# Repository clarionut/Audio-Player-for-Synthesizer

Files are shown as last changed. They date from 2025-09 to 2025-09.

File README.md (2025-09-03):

# Audio Player for Synthesizer
An audio player for a modular synthesizer based on a cheap 'Kebidu music speakers' module with FM radio, USB, micro SD, Bluetooth and aux-in modes.
This was inspired by the [Tesseract Modular 'Low Coast'](https://www.tesseractmodular.com/eurorack-modules/low-coast/) module which simply provides two Eurorack-level outputs, one for each of the stereo channels of the module.

This version also provides a mono mix output and has trigger inputs for the transport controls - play/pause, next station/track & previous station/track.

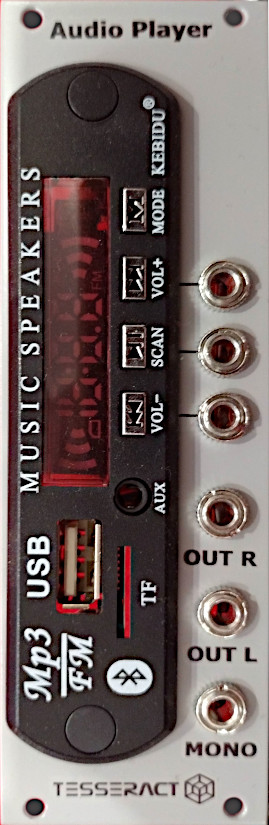
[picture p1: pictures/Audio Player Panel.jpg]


I'm not sure that this will be a particularly useful synth module, but I wanted to experiment using FETs as switches to allow external control. Somewhat to my surprise this works perfectly, with the switches being triggered by the rising edge of input pulses. Also the Kebidu units are very cheap - I got two for around £5 including shipping.

### Details
The Schematics folder contains pictures of the kicad schematic, the stripboard layout I used to build the module and a proposed PCB layout. There are several copper-side links (shown in blue) on the stripboard layout including two hard to see ones from pins 8 and 14 of the TL074 to the 100k resistors. Note that I haven't had the PCB fabricated, so use this layout at your own risk! The kicad project itself is in the AudioPlayer folder.

The only tricky part of the build was soldering the source and drain legs of the 2N7000 FETs across the switches. The solder pads are very small, so a fine-tipped soldering iron and a steady hand are needed! I've included a [photo showing the orientation of the FETs](https://github.com/clarionut/Audio-Player-for-Synthesizer/blob/main/pictures/Audio%20Player%20FETs.jpg) on my module. The correct orientation can be checked by measuring the voltage across each switch with a high impedance voltmeter. The drain of the FET is soldered to the more positive end of the switch, source to the negative end and the gate connected to the circuit board with a flying lead.

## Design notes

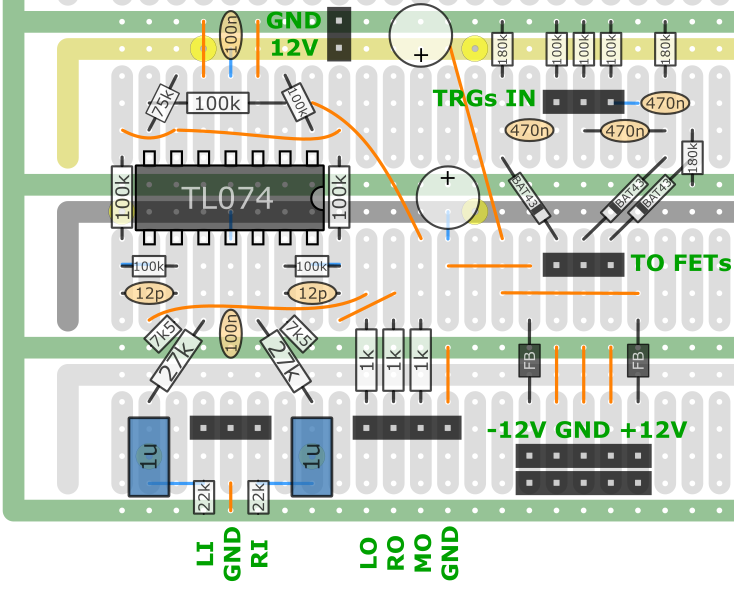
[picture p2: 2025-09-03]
schematics/layout.png

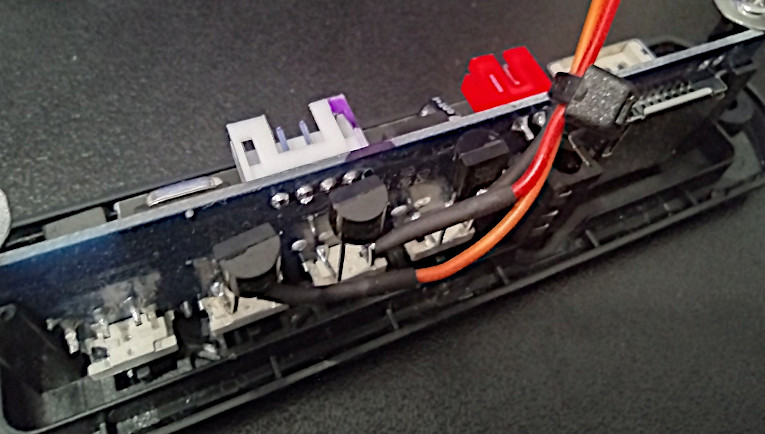
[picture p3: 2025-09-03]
pictures/Audio Player FETs.jpg

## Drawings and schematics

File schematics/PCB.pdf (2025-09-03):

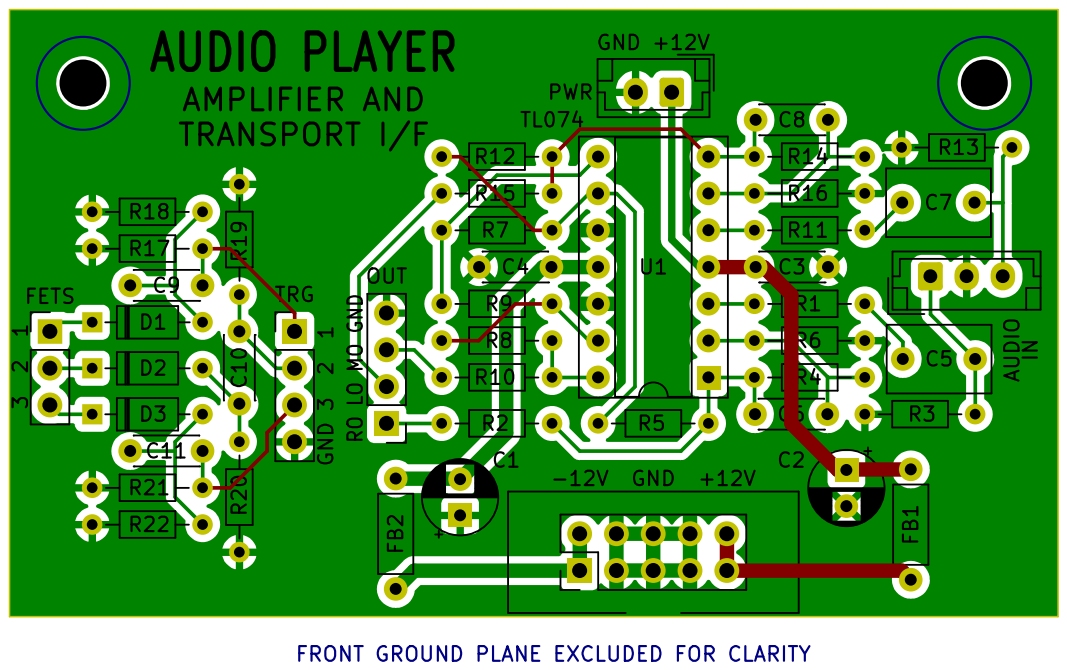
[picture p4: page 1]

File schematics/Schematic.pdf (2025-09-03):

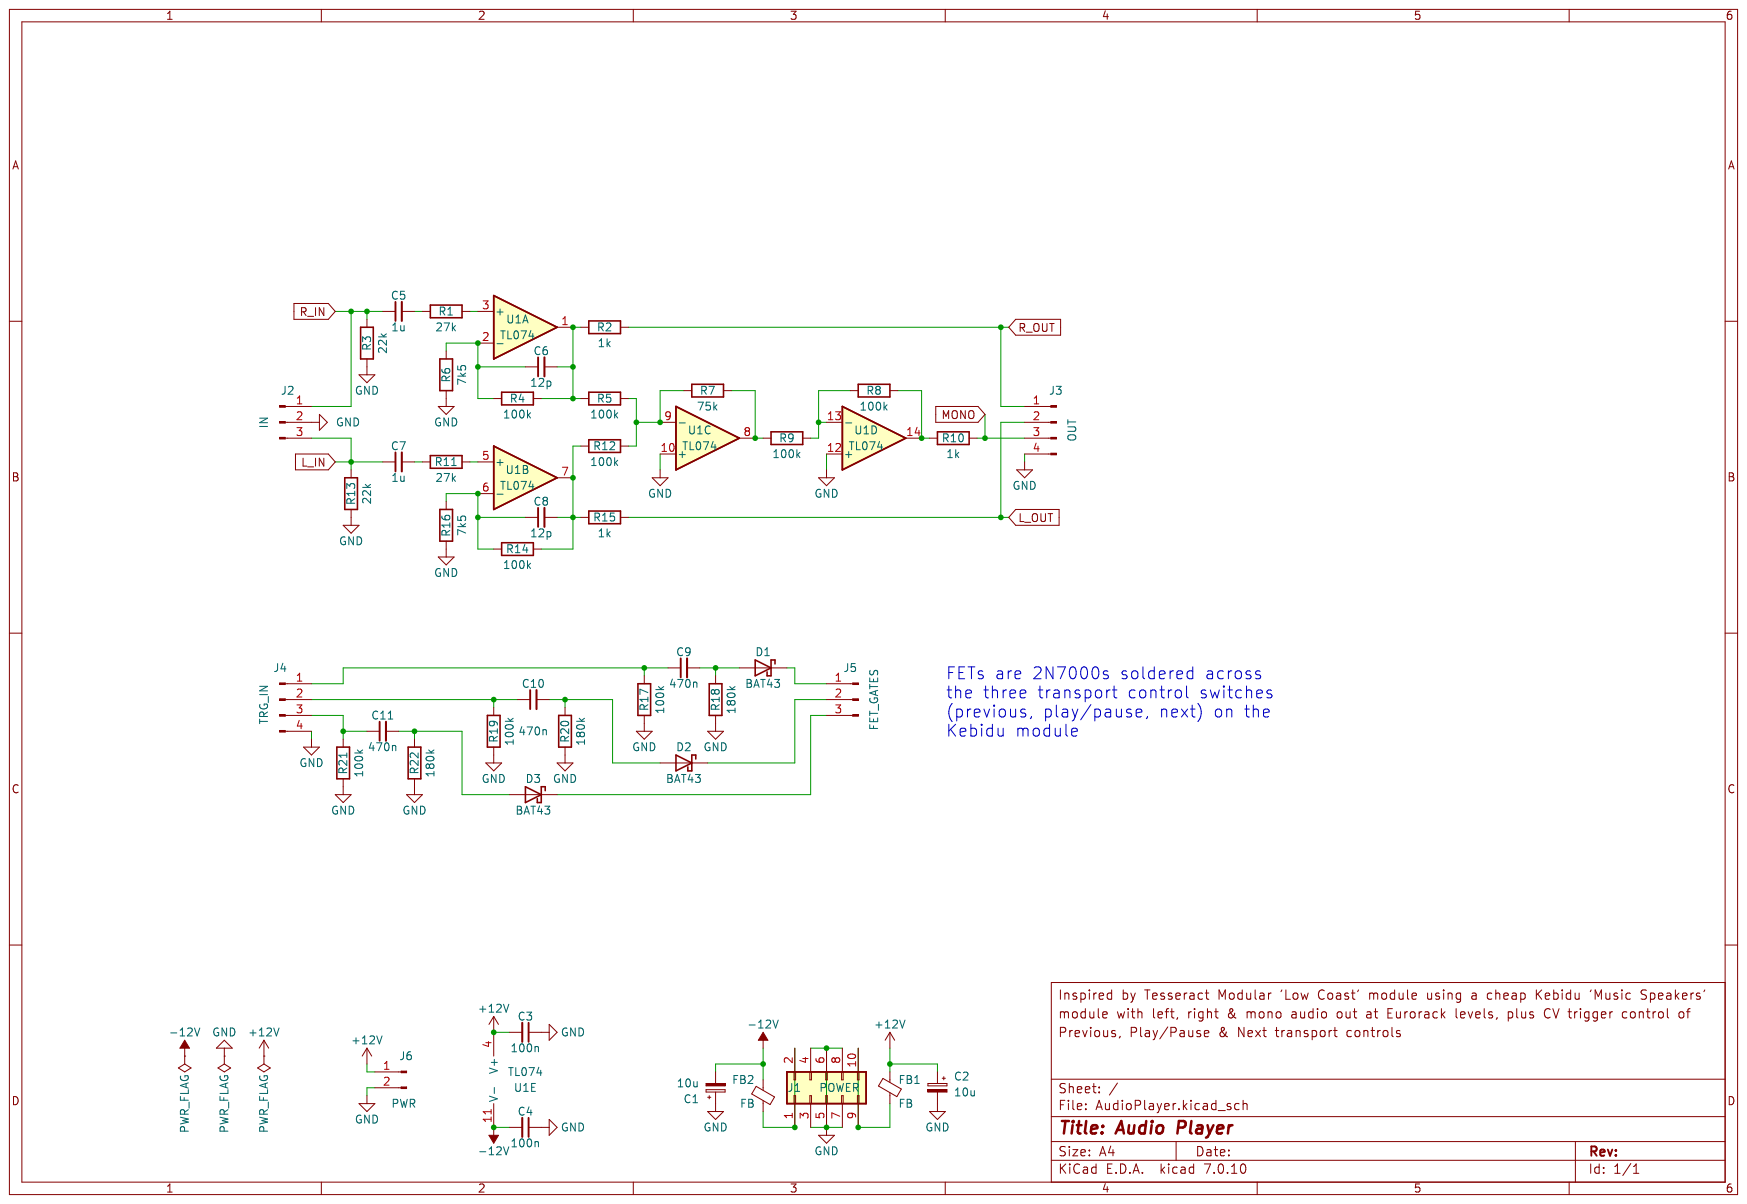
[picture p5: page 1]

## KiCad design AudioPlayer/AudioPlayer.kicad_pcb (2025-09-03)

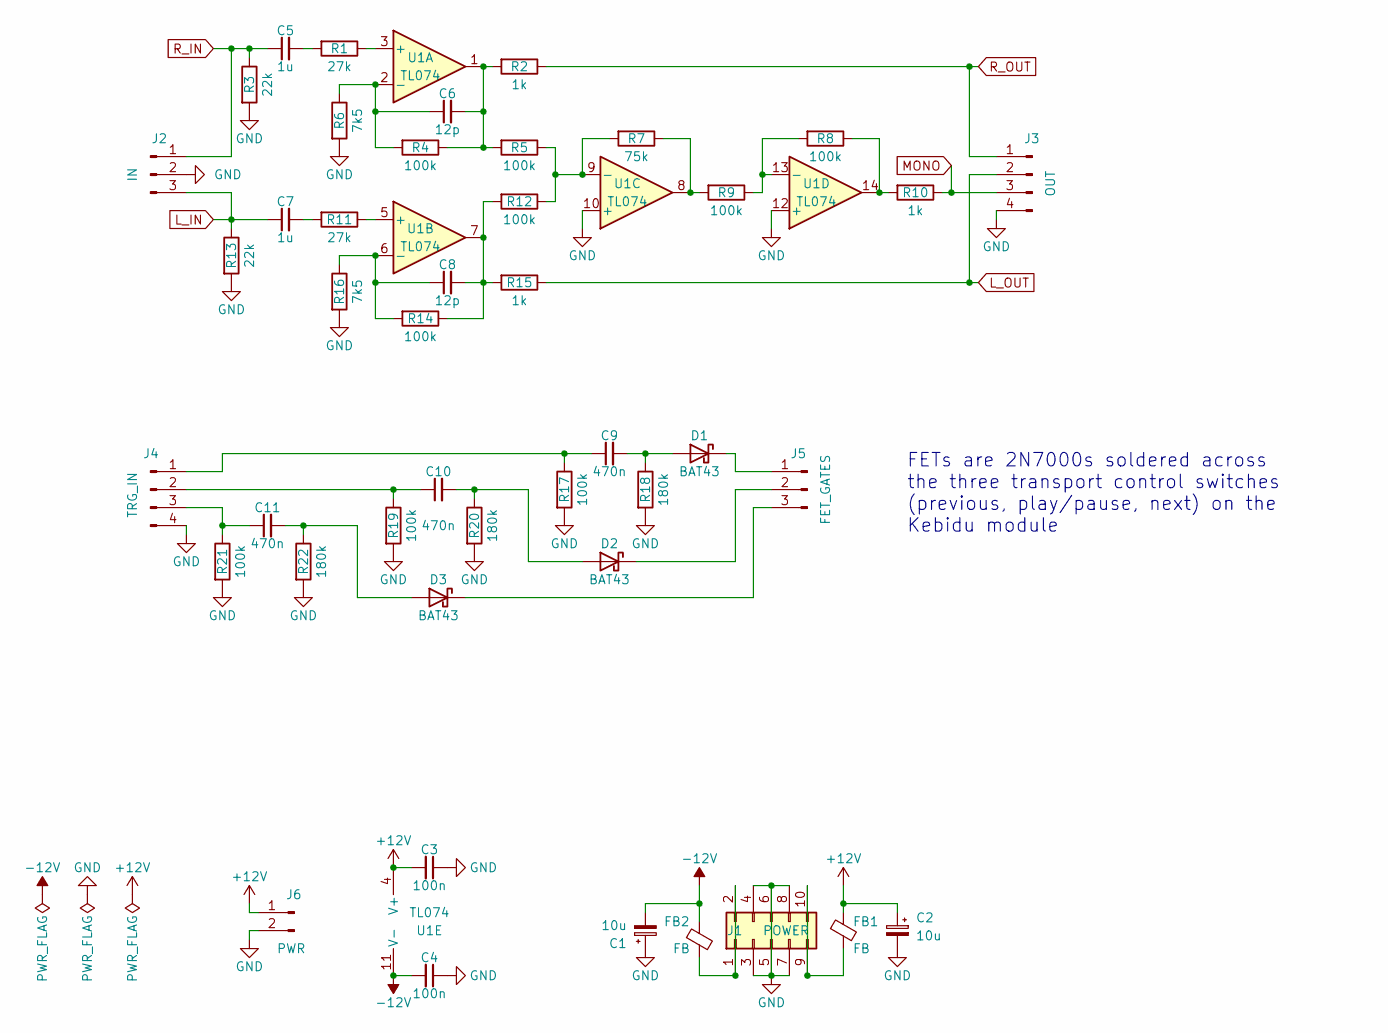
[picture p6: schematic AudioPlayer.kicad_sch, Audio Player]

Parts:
C1, C2: 10u; CP_Radial_D5.0mm_P2.50mm
C3, C4: 100n; C_Disc_D4.3mm_W1.9mm_P5.00mm
C5, C7: 1u; C_Rect_L7.0mm_W4.5mm_P5.00mm
C6, C8: 12p; C_Disc_D4.3mm_W1.9mm_P5.00mm
C9, C10, C11: 470n; C_Disc_D4.3mm_W1.9mm_P5.00mm
D1, D2, D3: BAT43; D_DO-35_SOD27_P7.62mm_Horizontal
FB1, FB2: FB; L_Axial_L5.3mm_D2.2mm_P7.62mm_Horizontal_Vishay_IM-1
J1: POWER; Power_2x05
J2: IN; JST_EH_B3B-EH-A_1x03_P2.50mm_Vertical
J3: OUT; PinHeader_1x04_P2.54mm_Vertical
J4: TRG_IN; PinHeader_1x04_P2.54mm_Vertical
J5: FET_GATES; PinHeader_1x03_P2.54mm_Vertical
J6: PWR; JST_EH_B2B-EH-A_1x02_P2.50mm_Vertical
R1, R11: 27k; R_Axial_DIN0204_L3.6mm_D1.6mm_P7.62mm_Horizontal
R2, R10, R15: 1k; R_Axial_DIN0204_L3.6mm_D1.6mm_P7.62mm_Horizontal
R3, R13: 22k; R_Axial_DIN0204_L3.6mm_D1.6mm_P7.62mm_Horizontal
R4, R5, R8, R9, R12, R14, R17, R19, R21: 100k; R_Axial_DIN0204_L3.6mm_D1.6mm_P7.62mm_Horizontal
R6, R16: 7k5; R_Axial_DIN0204_L3.6mm_D1.6mm_P7.62mm_Horizontal
R7: 75k; R_Axial_DIN0204_L3.6mm_D1.6mm_P7.62mm_Horizontal
R18, R20, R22: 180k; R_Axial_DIN0204_L3.6mm_D1.6mm_P7.62mm_Horizontal
U1: TL074; DIP-14_W7.62mm_Socket

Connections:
+12V: C2.1, C3.2, FB1.1, J6.1, U1.4 (V+)
-12V: C1.2, C4.2, FB2.1, U1.11 (V-)
GND: C1.1, C2.2, C3.1, C4.1, J1.3, J1.4, J1.5, J1.6, J1.7, J1.8, J2.2, J3.4, J4.4, J6.2, R3.2, R6.2, R13.2, R16.2, R17.2, R18.2, R19.2, R20.2, R21.2, R22.2, U1.10 (+), U1.12 (+)
L_IN: C7.1, J2.3, R13.1
L_OUT: J3.2, R15.1
MONO: J3.3, R10.1
unnamed: C5.2, R1.2
unnamed: C6.2, R2.2, R4.1, R5.2, U1.1
unnamed: C7.2, R11.2
unnamed: C8.2, R12.2, R14.1, R15.2, U1.7
unnamed: C9.2, D1.2 (A), R18.1
unnamed: D1.1 (K), J5.1
unnamed: C10.2, D2.2 (A), R20.1
unnamed: D2.1 (K), J5.2
unnamed: C11.2, D3.2 (A), R22.1
unnamed: D3.1 (K), J5.3
unnamed: FB2.2, J1.1, J1.2
unnamed: FB1.2, J1.9, J1.10
unnamed: C9.1, J4.1, R17.1
unnamed: C10.1, J4.2, R19.1
unnamed: C11.1, J4.3, R21.1
unnamed: R7.1, R9.2, U1.8
unnamed: R8.1, R10.2, U1.14
unnamed: R1.1, U1.3 (+)
unnamed: C6.1, R4.2, R6.1, U1.2 (-)
unnamed: R11.1, U1.5 (+)
unnamed: C8.1, R14.2, R16.1, U1.6 (-)
unnamed: R5.1, R7.2, R12.1, U1.9 (-)
unnamed: R8.2, R9.1, U1.13 (-)
R_IN: C5.1, J2.1, R3.1
R_OUT: J3.1, R2.1

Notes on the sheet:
FETs are 2N7000s soldered across the three transport control switches (previous, play/pause, next) on the Kebidu module

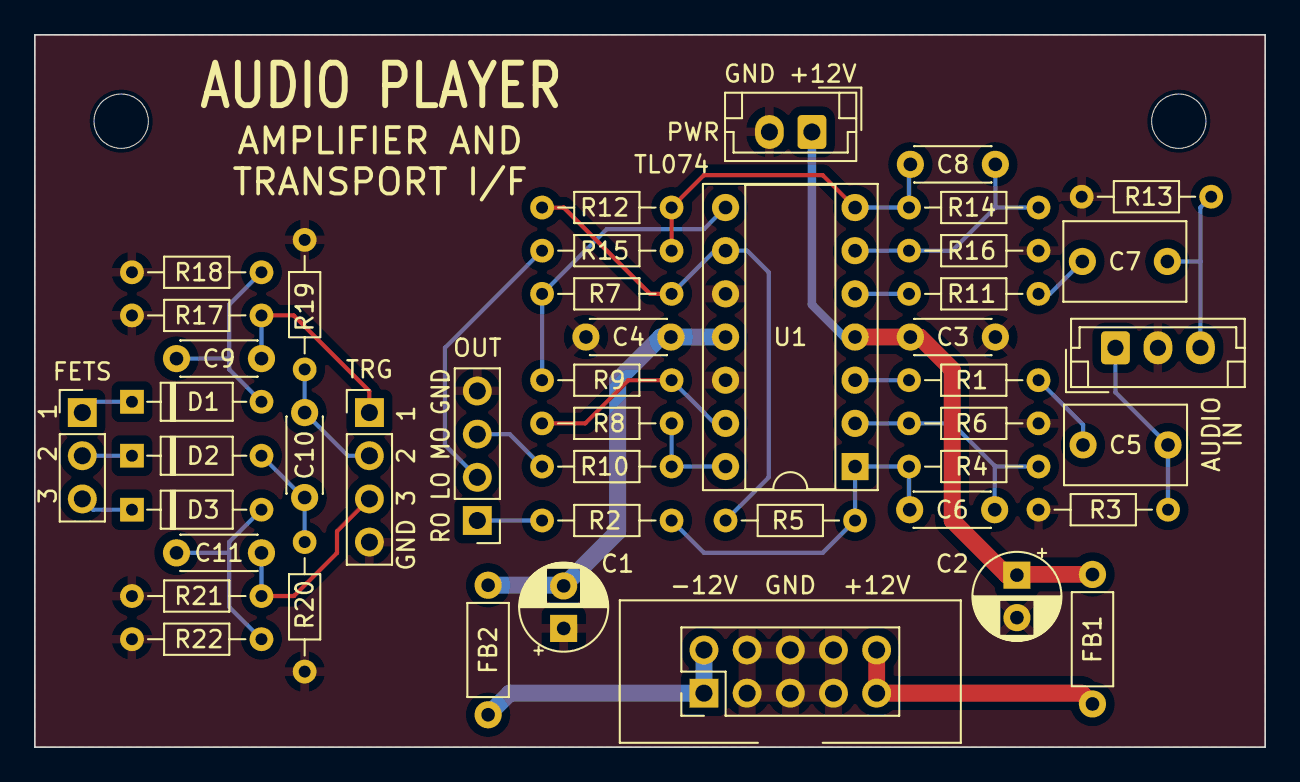
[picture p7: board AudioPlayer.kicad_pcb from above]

Board: 2 copper layers, 72.4 x 41.9 mm, 45 parts (0 on the bottom side), 31 nets.
